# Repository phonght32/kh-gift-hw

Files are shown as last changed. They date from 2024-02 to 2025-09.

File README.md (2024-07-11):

# kh-gift-hw

### 1. Overview

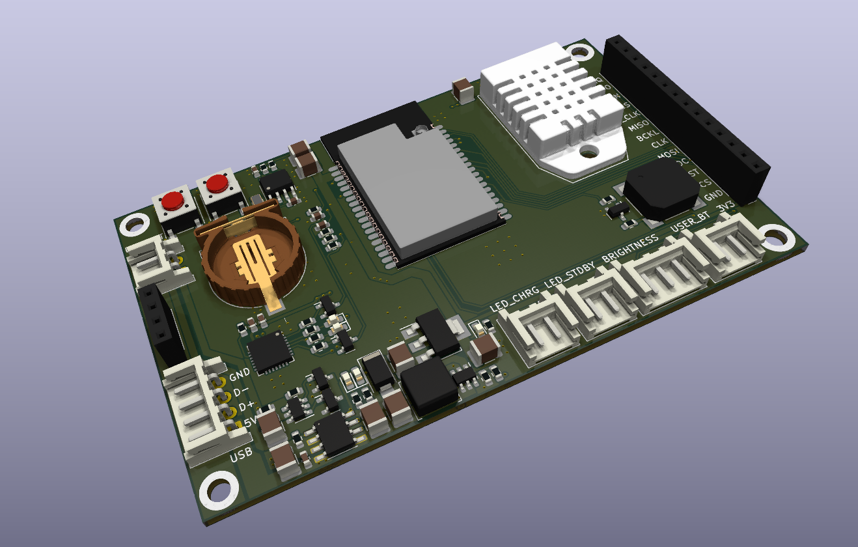
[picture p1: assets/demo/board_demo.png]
board_demo


### 2. Specifications

| Items | Specifications |
| --- | --- |
| Power supply | Pin LiPo 1 cell |
| Microcontroller  | ESP32 |
| LEDs and Buttons | LED Charge<br />LED Standby<br />User push button |
| Dimensions | 89.4 x55 mm<br />Screw hole 83.4 x 49 mm |

### 3. Hardware design

#### Schematic

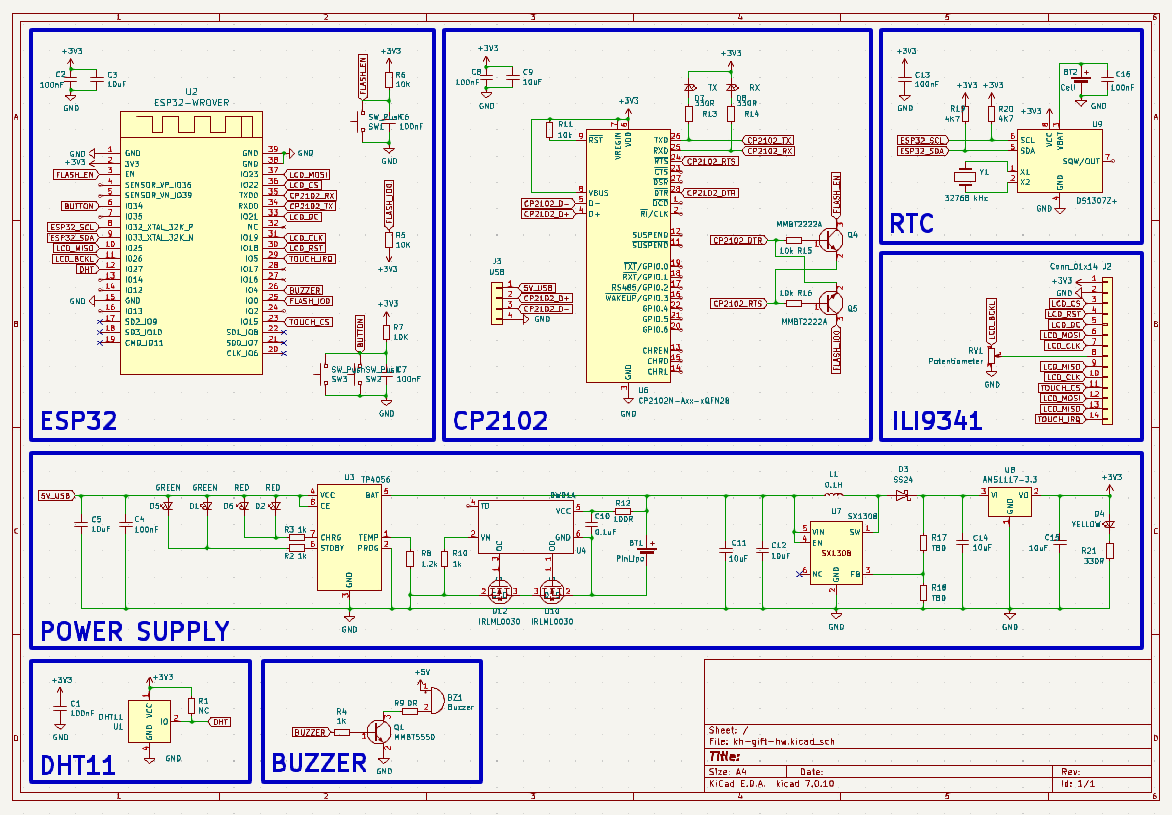
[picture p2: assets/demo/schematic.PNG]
schematic


#### PCB Top

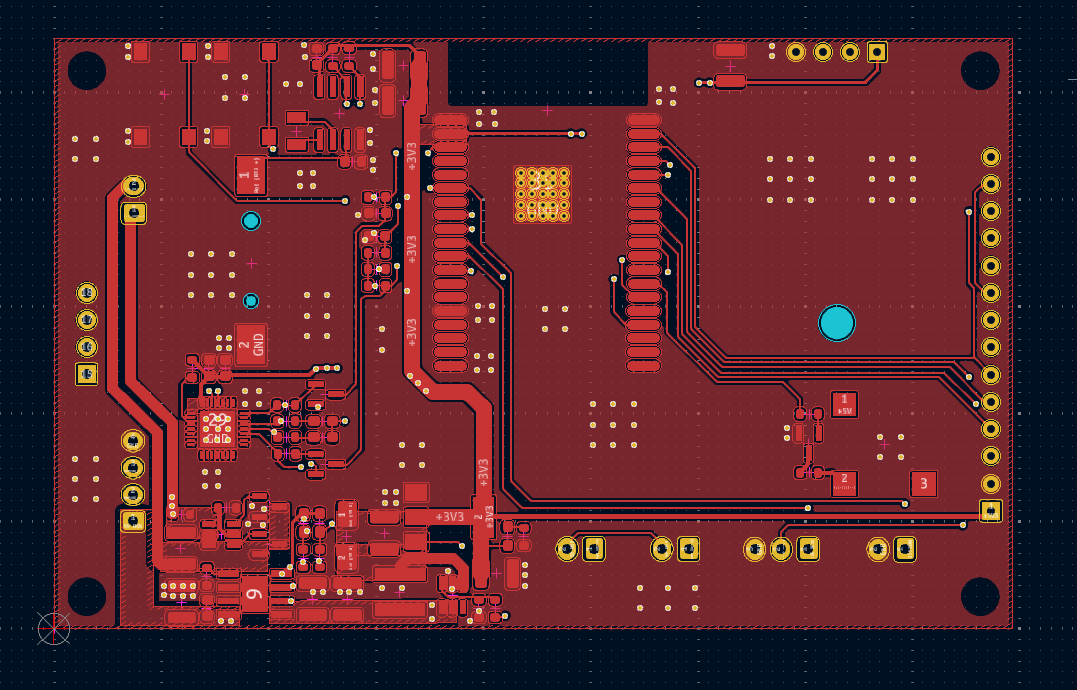
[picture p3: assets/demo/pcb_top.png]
pcb_top


#### PCB Bot

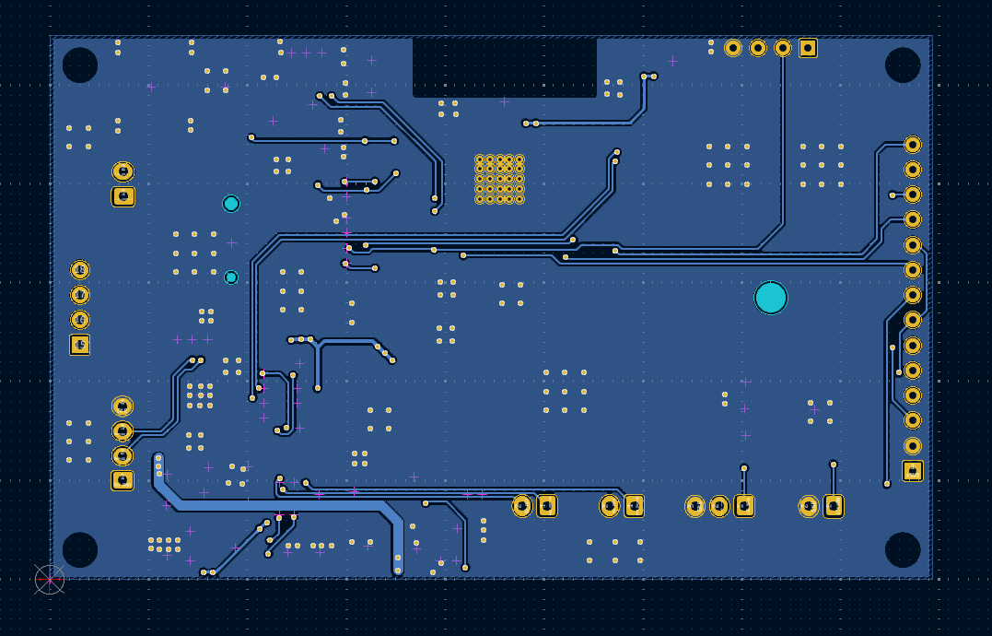
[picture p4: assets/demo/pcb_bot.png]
pcb_bot


#### Dimension

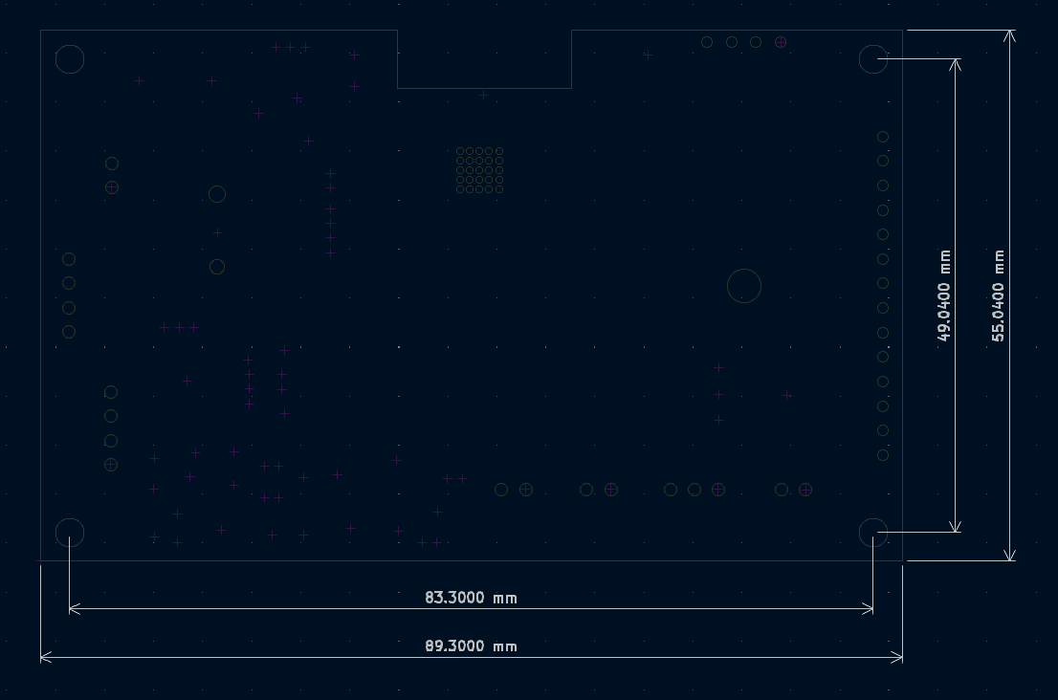
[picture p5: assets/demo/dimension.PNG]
dimension


#### 3D Top

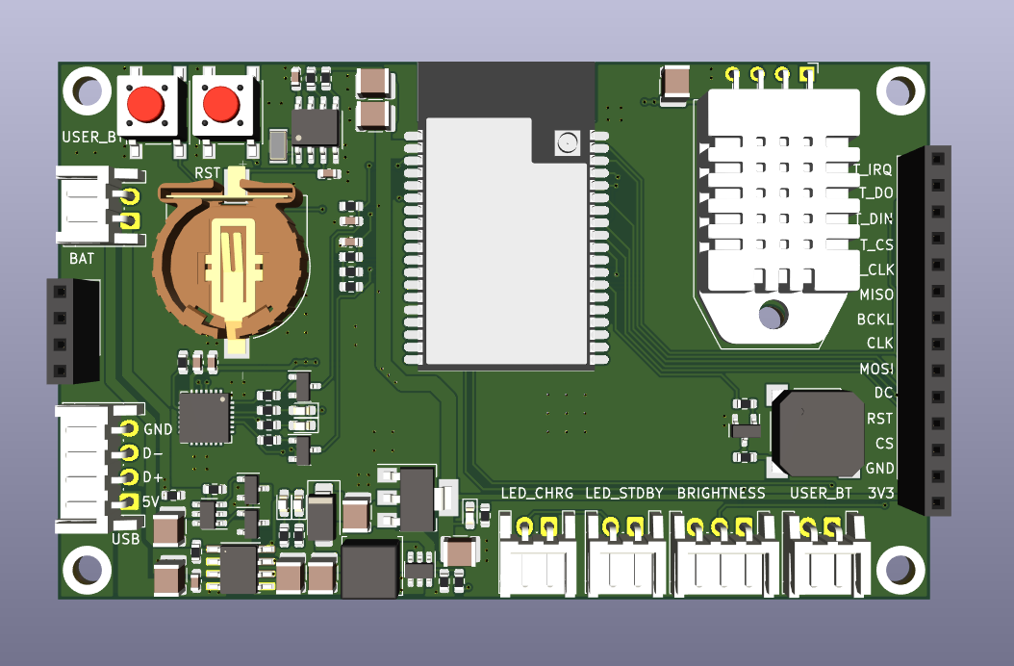
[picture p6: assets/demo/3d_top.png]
3d_top


#### 3D Bot

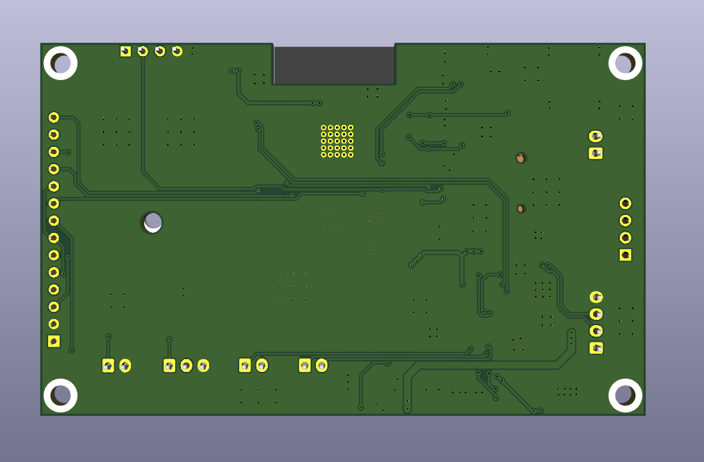
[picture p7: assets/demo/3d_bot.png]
3d_bot


### 4. Bill of Materials (BOM)

[Download v2.0](assets/BOM/BOM_kh-gift-hw_v2.0.xlsx)

### 5. Gerber

[Download v1.0](assets/Gerber/Gerber_kh-gift-hw_v1.0.zip)

[Download v2.0](assets/Gerber/Gerber_kh-gift-hw_v2.0.zip)

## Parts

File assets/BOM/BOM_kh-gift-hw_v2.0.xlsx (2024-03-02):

Reference | Value | Footprint | Qty
BT1 | PinLipo | footprints:JST_EH_S2B-EH_1x02_P2.5mm_Horizontal | 1
BT2 | Cell | footprints:BAT_CR1220_Holder | 1
BZ1 | Buzzer | Buzzer_Beeper:MagneticBuzzer_Kobitone_254-EMB84Q-RO | 1
C1,C2 | 100nF | Capacitor_SMD:C_1210_3225Metric | 2
C3,C5,C11,C12,C14,C15 | 10uF | Capacitor_SMD:C_1210_3225Metric | 6
C4,C6,C7,C8,C13,C16 | 100nF | Capacitor_SMD:C_0603_1608Metric | 6
C9 | 10uF | Capacitor_SMD:C_0603_1608Metric | 1
C10 | 0.1uF | Capacitor_SMD:C_1210_3225Metric | 1
D1 | GREEN | LED_SMD:LED_0603_1608Metric_Pad1.05x0.95mm_HandSolder | 1
D2 | RED | LED_SMD:LED_0603_1608Metric_Pad1.05x0.95mm_HandSolder | 1
D3 | SS24 | Diode_SMD:D_SMA | 1
D4 | YELLOW | LED_SMD:LED_0603_1608Metric_Pad1.05x0.95mm_HandSolder | 1
D5 | GREEN | footprints:JST_EH_S2B-EH_1x02_P2.5mm_Horizontal | 1
D6 | RED | footprints:JST_EH_S2B-EH_1x02_P2.5mm_Horizontal | 1
D7 | TX | LED_SMD:LED_0603_1608Metric_Pad1.05x0.95mm_HandSolder | 1
D8 | RX | LED_SMD:LED_0603_1608Metric_Pad1.05x0.95mm_HandSolder | 1
J2 | Conn_01x14 | footprints:ili9341_3.2inch | 1
J3 | USB | footprints:JST_EH_S4B-EH_1x04_P2.5mm_Horizontal | 1
L1 | 0.1H | Inductor_SMD:L_Coilcraft_XAL5030-XXX | 1
Q1 | MMBT5550 | Package_TO_SOT_SMD:SOT-23 | 1
Q4,Q5 | MMBT2222A | Package_TO_SOT_SMD:SOT-23 | 2
R1 | NC | Resistor_SMD:R_0603_1608Metric | 1
R2,R3,R10 | 1k | Resistor_SMD:R_0603_1608Metric | 3
R4 | 1K | Resistor_SMD:R_0603_1608Metric | 1
R5,R6,R7 | 10K | Resistor_SMD:R_0603_1608Metric | 3
R8 | 1.2k | Resistor_SMD:R_0603_1608Metric | 1
R9 | 0R | Resistor_SMD:R_0603_1608Metric | 1
R11,R15,R16 | 10k | Resistor_SMD:R_0603_1608Metric | 3
R12 | 100R | Resistor_SMD:R_0603_1608Metric | 1
R13,R14,R21 | 330R | Resistor_SMD:R_0603_1608Metric | 3
R17,R18 | TBD | Resistor_SMD:R_0603_1608Metric | 2
R19,R20 | 4K7 | Resistor_SMD:R_0603_1608Metric | 2
RV1 | Potentiometer | footprints:JST_EH_S3B-EH_1x03_P2.5mm_Horizontal | 1
SW1,SW2 | SW_Push | footprints:PushButton_6x6mm_SMD | 2
SW3 | SW_Push | footprints:JST_EH_S2B-EH_1x02_P2.5mm_Horizontal | 1
U1 | DHT11 | footprints:SNR4-2.54-15.5X12.0X5.5MM | 1
U2 | ESP32-WROVER | footprints:ESP32-WROVER | 1
U3 | TP4056 | footprints:SOP127P600X175-9N | 1
U4 | DW01A | Package_TO_SOT_SMD:TSOT-23-6 | 1
U6 | CP2102N-Axx-xQFN28 | Package_DFN_QFN:QFN-28-1EP_5x5mm_P0.5mm_EP3.35x3.35mm | 1
U7 | SX1308 | Package_TO_SOT_SMD:TSOT-23-6 | 1
U8 | AMS1117-3.3 | Package_TO_SOT_SMD:SOT-223-3_TabPin2 | 1
U9 | DS1307Z+ | Package_SO:SOIC-8_3.9x4.9mm_P1.27mm | 1
U10,U12 | IRLML0030 | Package_TO_SOT_SMD:SOT-23 | 2
Y1 | 32768 kHz | footprints:Crystal_SMD_3215-2Pin_3.2x1.5mm | 1

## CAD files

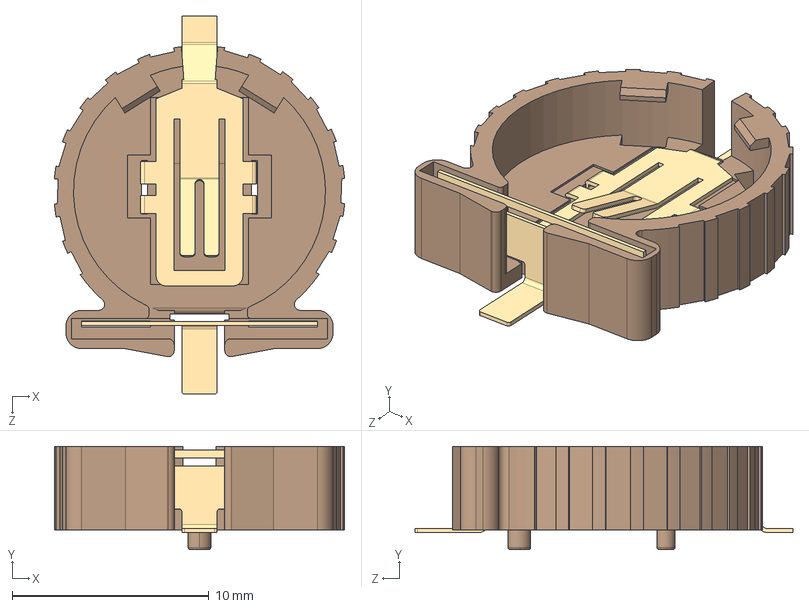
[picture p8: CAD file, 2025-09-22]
Project-Lib/3D/PinHolder_CR1220_SMD.STEP
14.7 x 5.25 x 19.2 mm
S841-HOLDER
S841-LOWER-CONTACT
S841-REAR-CONTACT

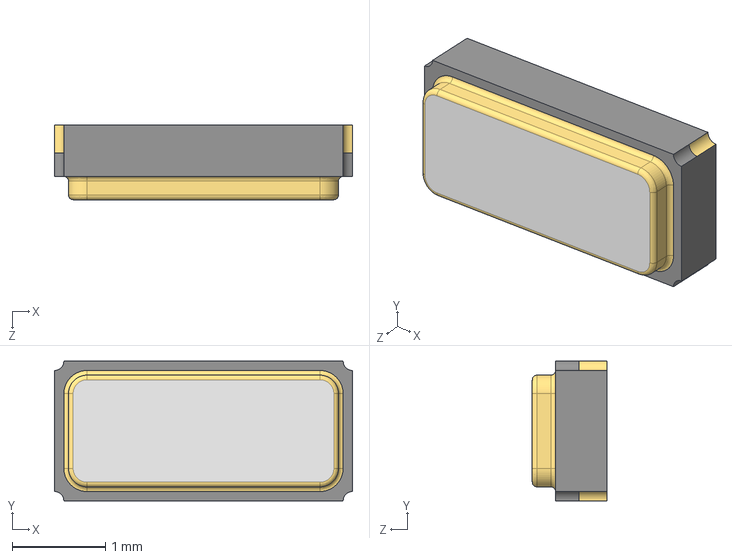
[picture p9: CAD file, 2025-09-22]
Project-Lib/3D/crystal_smd_3215.step
3.20 x 1.50 x 0.8 mm

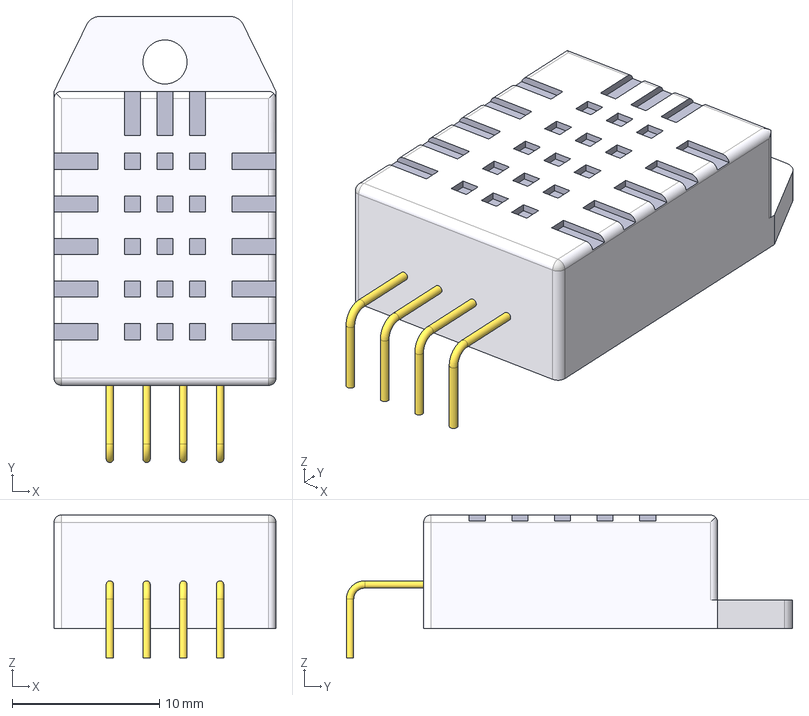
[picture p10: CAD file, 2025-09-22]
Project-Lib/3D/DHT22.stp
15.1 x 30.3 x 9.72 mm

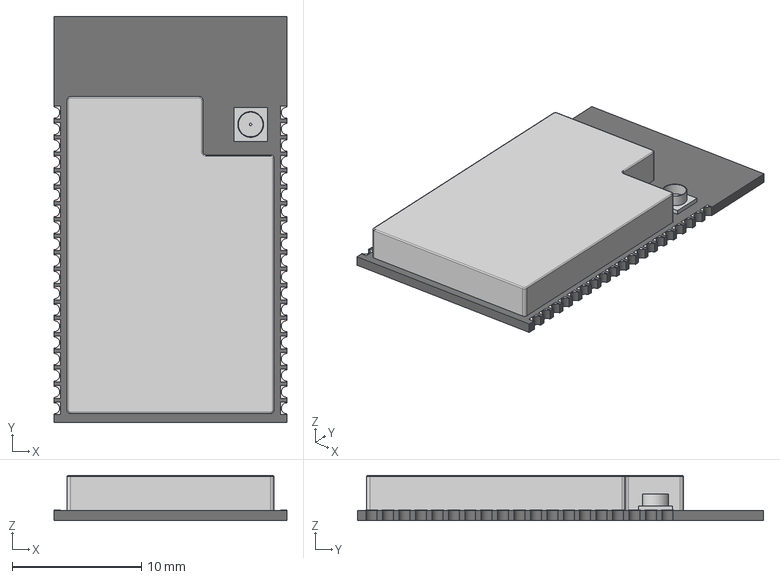
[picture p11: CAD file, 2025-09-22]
Project-Lib/3D/ESP32-Wrover.step
18.0 x 31.4 x 3.50 mm

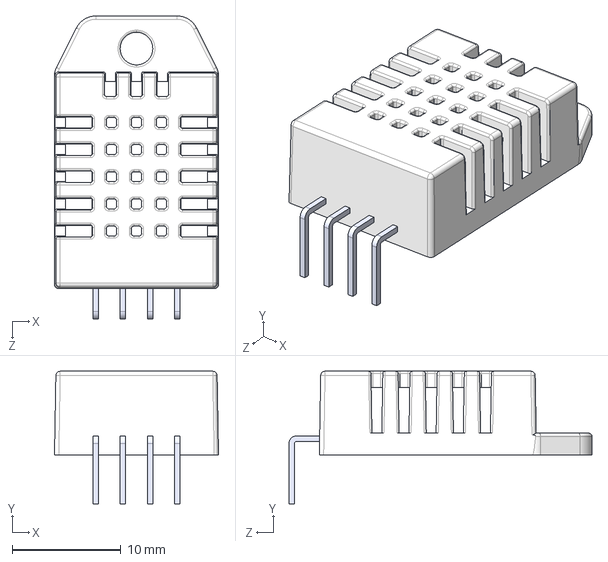
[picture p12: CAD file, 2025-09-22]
Project-Lib/3D/DHT22--3DModel-STEP-56544.STEP
15.1 x 12.2 x 27.9 mm
DHT22 body
pin^DHT22 x 4

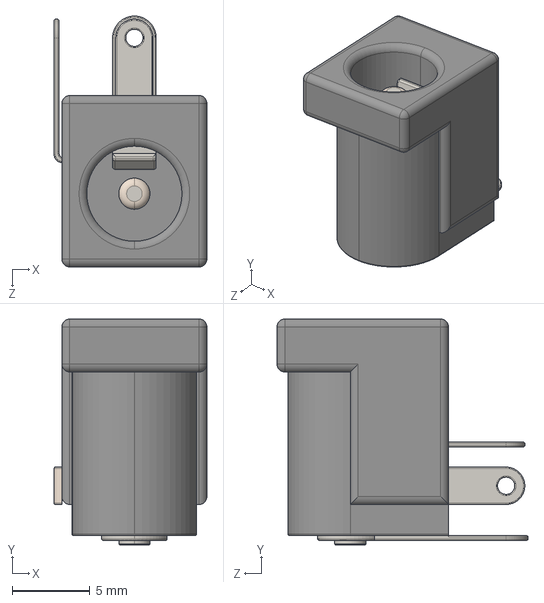
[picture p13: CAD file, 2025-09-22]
Project-Lib/3D/JackDC_5.5mmx2.1mm.step
9.80 x 14.5 x 16.1 mm

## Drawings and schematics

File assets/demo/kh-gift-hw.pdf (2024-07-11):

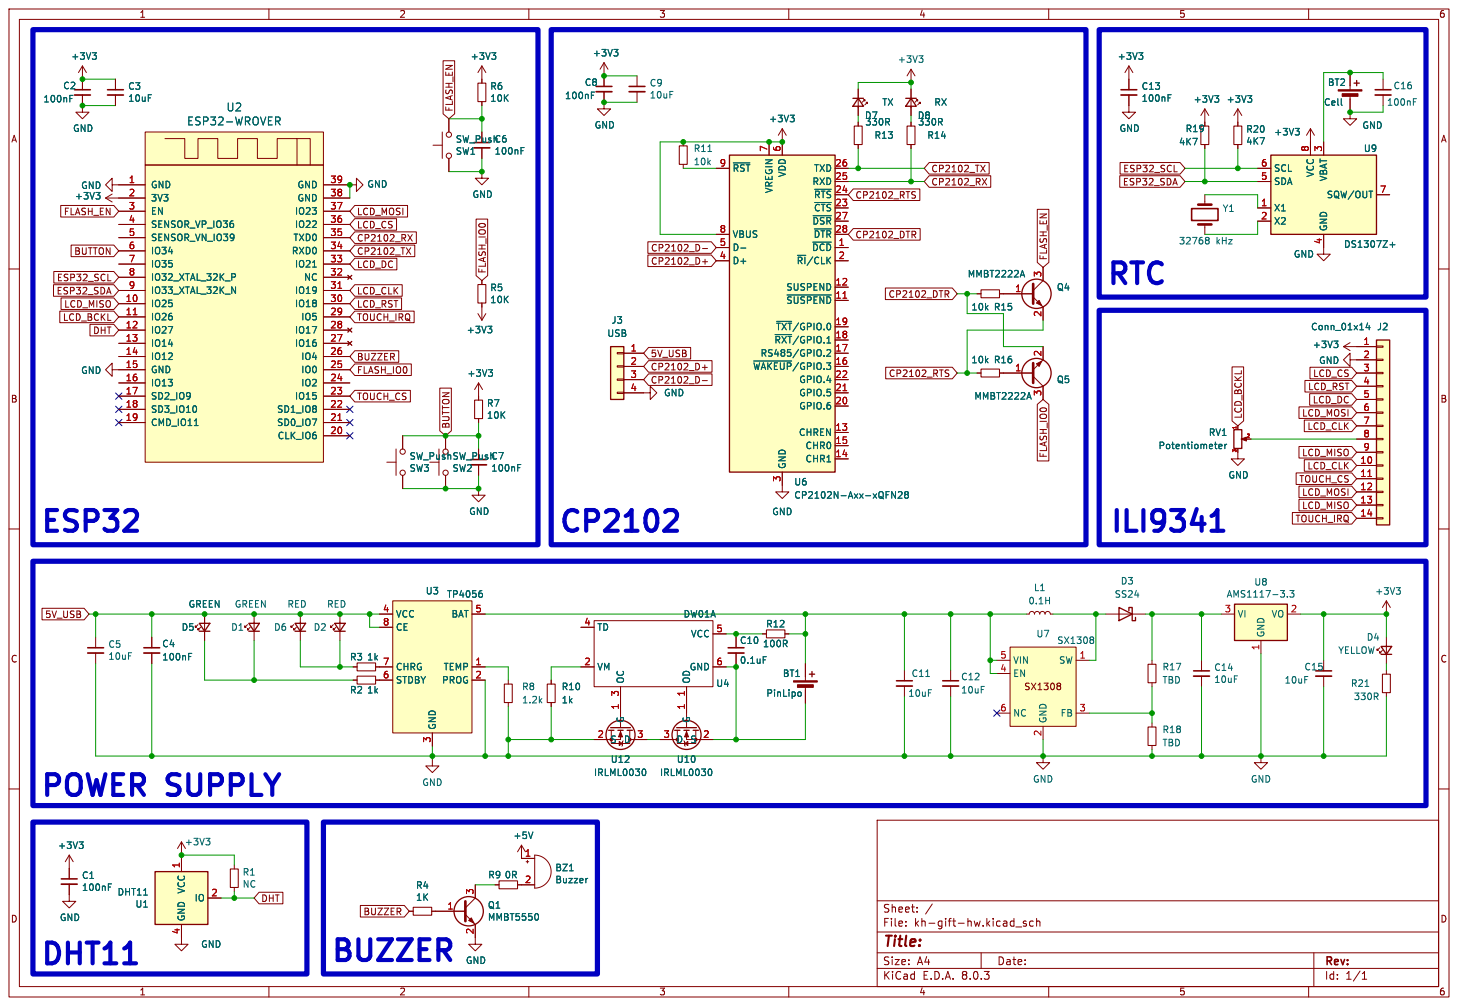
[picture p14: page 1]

7 VBUS 8 ~{RST} 9 U6 CP2102N-Axx-xQFN28 D6 RED GND

4 SDA 5 SCL 6 SQW/OUT 7 VCC

3 VCC 4 BAT 5 STDBY 6 CHRG 7 CE 8 SW3 SW_Push R10

3 VCC 4 BAT 5 STDBY 6 CHRG 7 CE 8 U3 TP4056 C15

2 FB 3 EN 4 VIN 5 NC 6 U7 SX1308 C12

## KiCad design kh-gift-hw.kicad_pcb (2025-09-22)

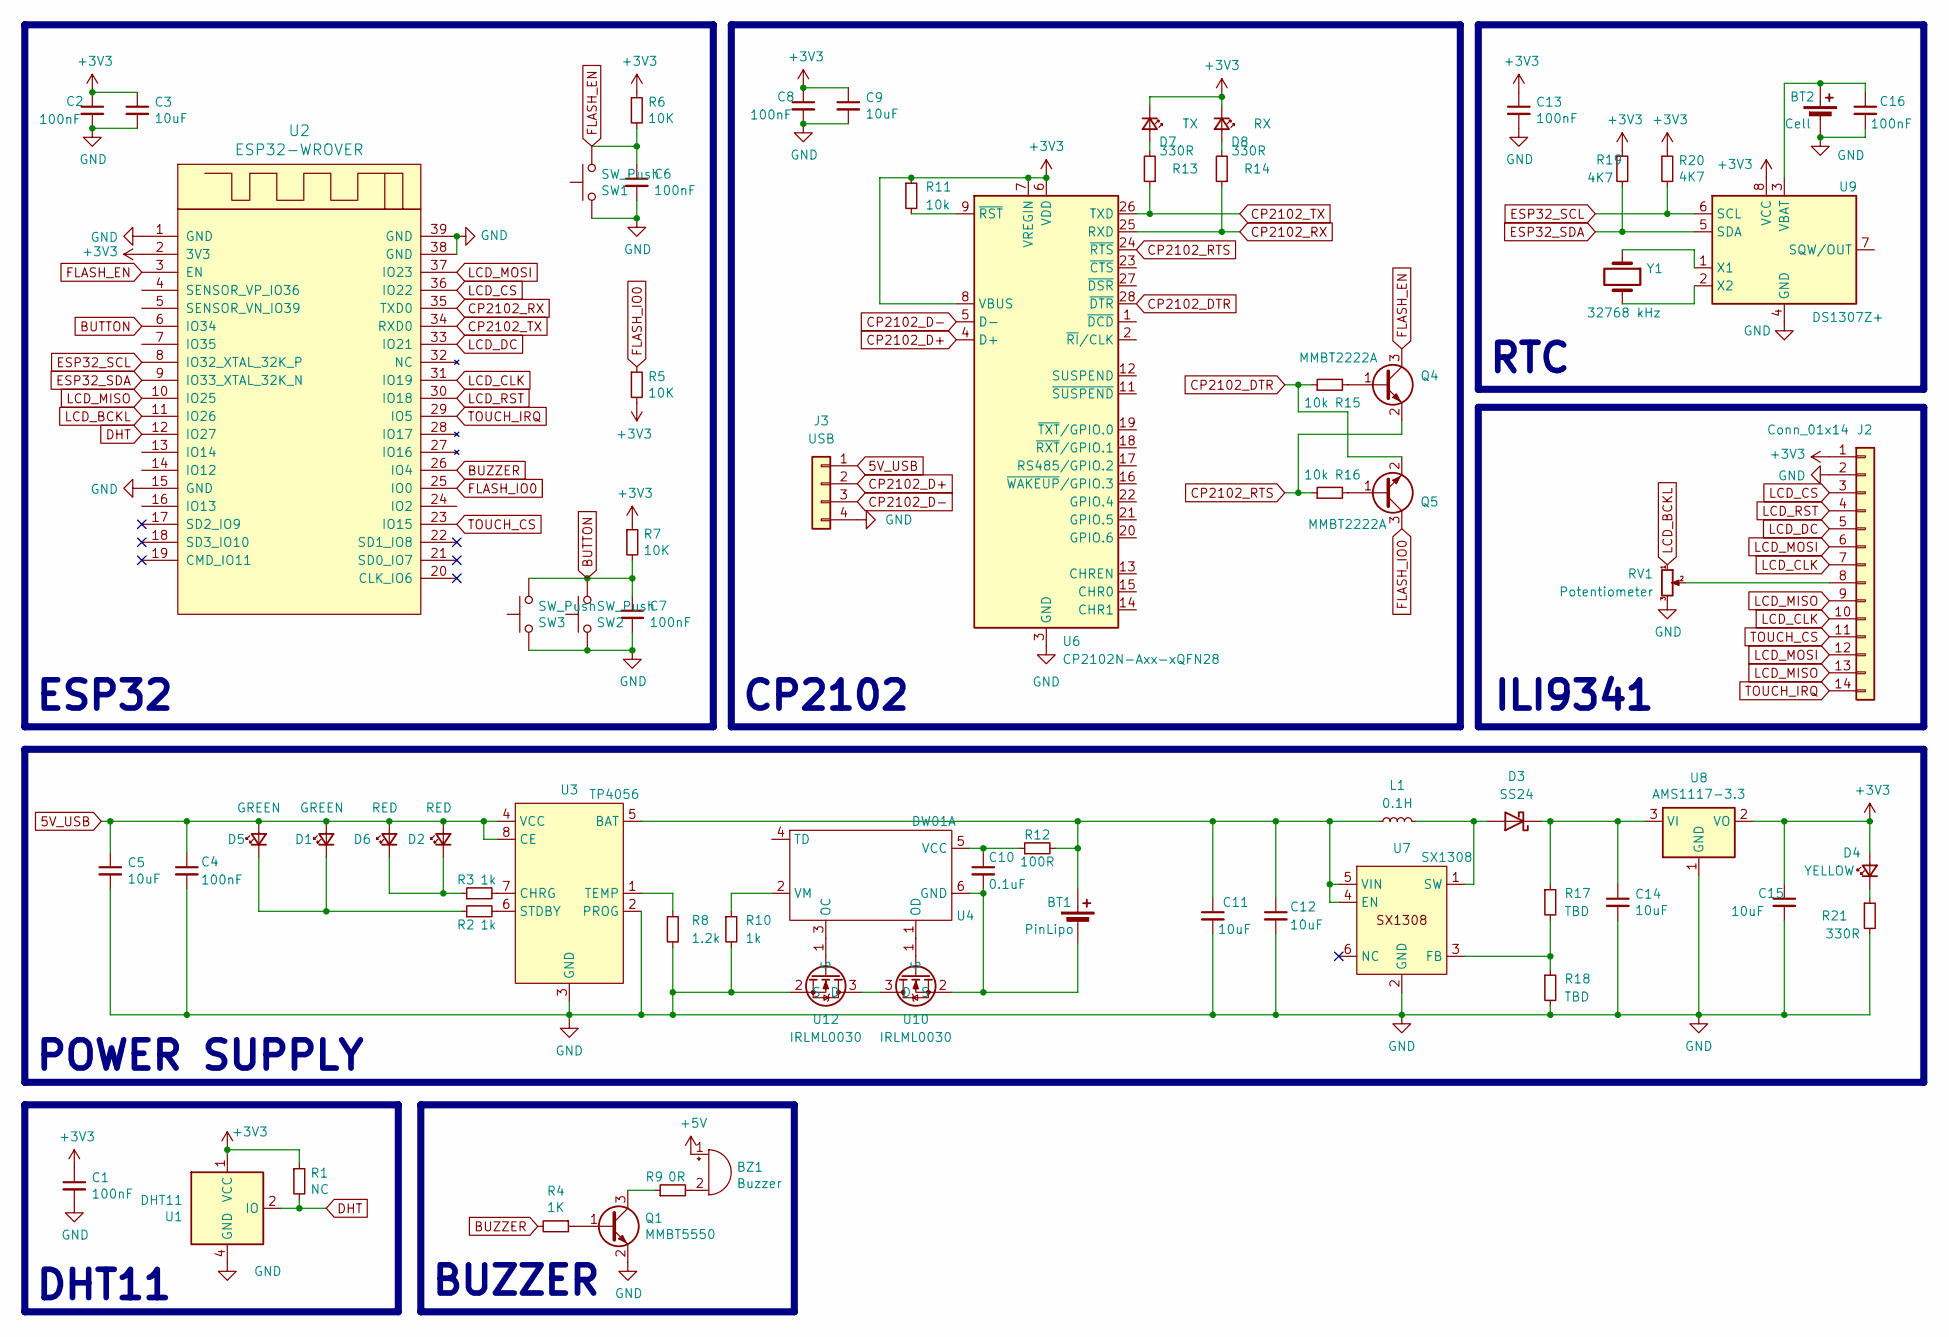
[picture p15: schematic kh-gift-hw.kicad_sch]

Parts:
BT1: PinLipo; JST_EH_S2B-EH_1x02_P2.5mm_Horizontal
BT2: Cell; BAT_CR1220_Holder
BZ1: Buzzer; MagneticBuzzer_Kobitone_254-EMB84Q-RO
C1, C2: 100nF; C_1210_3225Metric
C3, C5, C11, C12, C14, C15: 10uF; C_1210_3225Metric
C4, C6, C7, C8, C13, C16: 100nF; C_0603_1608Metric
C9: 10uF; C_0603_1608Metric
C10: 0.1uF; C_1210_3225Metric
D1: GREEN; LED_0603_1608Metric_Pad1.05x0.95mm_HandSolder
D2: RED; LED_0603_1608Metric_Pad1.05x0.95mm_HandSolder
D3: SS24; D_SMA
D4: YELLOW; LED_0603_1608Metric_Pad1.05x0.95mm_HandSolder
D5: GREEN; Connector_ZH_1x02_P1.25mm_Horizontal
D6: RED; Connector_ZH_1x02_P1.25mm_Horizontal
D7: TX; LED_0603_1608Metric_Pad1.05x0.95mm_HandSolder
D8: RX; LED_0603_1608Metric_Pad1.05x0.95mm_HandSolder
J2: Conn_01x14; ili9341_3.2inch
J3: USB; JST_EH_S4B-EH_1x04_P2.5mm_Horizontal
L1: 0.1H; L_Coilcraft_XAL5030-XXX
Q1: MMBT5550; SOT-23
Q4, Q5: MMBT2222A; SOT-23
R1: NC; R_0603_1608Metric
R2, R3, R10: 1k; R_0603_1608Metric
R4: 1K; R_0603_1608Metric
R5, R6, R7: 10K; R_0603_1608Metric
R8: 1.2k; R_0603_1608Metric
R9: 0R; R_0603_1608Metric
R11, R15, R16: 10k; R_0603_1608Metric
R12: 100R; R_0603_1608Metric
R13, R14, R21: 330R; R_0603_1608Metric
R17, R18: TBD; R_0603_1608Metric
R19, R20: 4K7; R_0603_1608Metric
RV1: Potentiometer; Connector_ZH_1x03_P1.25mm_Horizontal
SW1, SW2: SW_Push; PushButton_6x6mm_SMD
SW3: SW_Push; Connector_ZH_1x02_P1.25mm_Horizontal
U1: DHT11; SNR4-2.54-15.5X12.0X5.5MM
U2: ESP32-WROVER
U3: TP4056; SOP127P600X175-9N
U4: DW01A; TSOT-23-6
U6: CP2102N-Axx-xQFN28; QFN-28-1EP_5x5mm_P0.5mm_EP3.35x3.35mm
U7: SX1308; TSOT-23-6
U8: AMS1117-3.3; SOT-223-3_TabPin2
U9: DS1307Z+; SOIC-8_3.9x4.9mm_P1.27mm
U10, U12: IRLML0030; SOT-23
Y1: 32768 kHz; Crystal_SMD_3215-2Pin_3.2x1.5mm

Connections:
5V_USB: C4.1, C5.1, D1.2 (A), D2.2 (A), D5.2 (A), D6.2 (A), J3.1, U3.4 (VCC), U3.8 (CE)
+3V3: C1.1, C2.1, C3.1, C8.1, C9.1, C13.1, C15.1, D4.2 (A), D7.1 (K), D8.1 (K), J2.1, R1.1, R5.2, R6.1, R7.1, R11.1, R19.1, R20.1, U1.1 (VCC), U2.2 (3V3), U6.6 (VDD), U6.7 (VREGIN), U6.8 (VBUS), U8.2 (VO), U9.8 (VCC)
+5V: BZ1.1 (-)
BUTTON: C7.1, R7.2, SW2.1, SW3.1, U2.6 (IO34)
BUZZER: R4.2, U2.26 (IO4)
CP2102_D+: J3.2, U6.4 (D+)
CP2102_D-: J3.3, U6.5 (D-)
CP2102_DTR: Q5.2 (E), R15.1, U6.28 (~DTR)
CP2102_RTS: Q4.2 (E), R16.1, U6.24 (~RTS)
CP2102_RX: R14.1, U2.35 (TXD0), U6.25 (RXD)
CP2102_TX: R13.1, U2.34 (RXD0), U6.26 (TXD)
DHT: R1.2, U1.2 (IO), U2.12 (IO27)
ESP32_SCL: R20.2, U2.8 (IO32_XTAL_32K_P), U9.6 (SCL)
ESP32_SDA: R19.2, U2.9 (IO33_XTAL_32K_N), U9.5 (SDA)
FLASH_EN: C6.1, Q4.3 (C), R6.2, SW1.1, U2.3 (EN)
FLASH_IO0: Q5.3 (C), R5.1, U2.25 (IO0)
GND: BT2.2 (-), C1.2, C2.2, C3.2, C4.2, C5.2, C6.2, C7.2, C8.2, C9.2, C11.2, C12.2, C13.2, C14.2, C15.2, C16.2, J2.2, J3.4, Q1.2 (E), R8.2, R10.2, R18.2, R21.2, RV1.3, SW1.2, SW2.2, SW3.2, U1.4 (GND), U2.1 (GND), U2.15 (GND), U2.38 (GND), U2.39 (GND), U3.2 (PROG), U3.3 (GND), U6.3 (GND), U6.29 (GND), U7.2 (GND), U8.1 (GND), U9.4 (GND), U12.2 (S)
LCD_BCKL: RV1.1, U2.11 (IO26)
LCD_CLK: J2.7, J2.10, U2.31 (IO19)
LCD_CS: J2.3, U2.36 (IO22)
LCD_DC: J2.5, U2.33 (IO21)
LCD_MISO: J2.9, J2.13, U2.10 (IO25)
LCD_MOSI: J2.6, J2.12, U2.37 (IO23)
LCD_RST: J2.4, U2.30 (IO18)
unnamed: BT1.1 (+), C11.1, C12.1, L1.1, R12.2, U3.5 (BAT), U7.4 (EN), U7.5 (VIN)
unnamed: BT1.2 (-), C10.2, U4.6 (GND), U10.2 (S)
unnamed: BT2.1 (+), C16.1, U9.3 (VBAT)
unnamed: BZ1.2 (+), R9.2
unnamed: D1.1 (K), D5.1 (K), R2.1
unnamed: D2.1 (K), D6.1 (K), R3.1
unnamed: D3.2 (A), L1.2, U7.1 (SW)
unnamed: C14.1, D3.1 (K), R17.1, U8.3 (VI)
unnamed: D4.1 (K), R21.1
unnamed: D7.2 (A), R13.2
unnamed: D8.2 (A), R14.2
unnamed: J2.8, RV1.2
unnamed: Q1.1 (B), R4.1
unnamed: Q1.3 (C), R9.1
unnamed: Q4.1 (B), R15.2
unnamed: Q5.1 (B), R16.2
unnamed: R3.2, U3.7 (CHRG)
unnamed: R2.2, U3.6 (STDBY)
unnamed: R8.1, U3.1 (TEMP)
unnamed: C10.1, R12.1, U4.5 (VCC)
unnamed: R10.1, U4.2 (VM)
unnamed: R11.2, U6.9 (~RST)
unnamed: R17.2, R18.1, U7.3 (FB)
unnamed: U9.1 (X1), Y1.1
unnamed: U9.2 (X2), Y1.2
unnamed: U10.3 (D), U12.3 (D)
unnamed: U4.1 (OD), U10.1 (G)
unnamed: U4.3 (OC), U12.1 (G)
TOUCH_CS: J2.11, U2.23 (IO15)
TOUCH_IRQ: J2.14, U2.29 (IO5)

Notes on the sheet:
ESP32
RTC
POWER SUPPLY
DHT11
ILI9341
BUZZER
CP2102

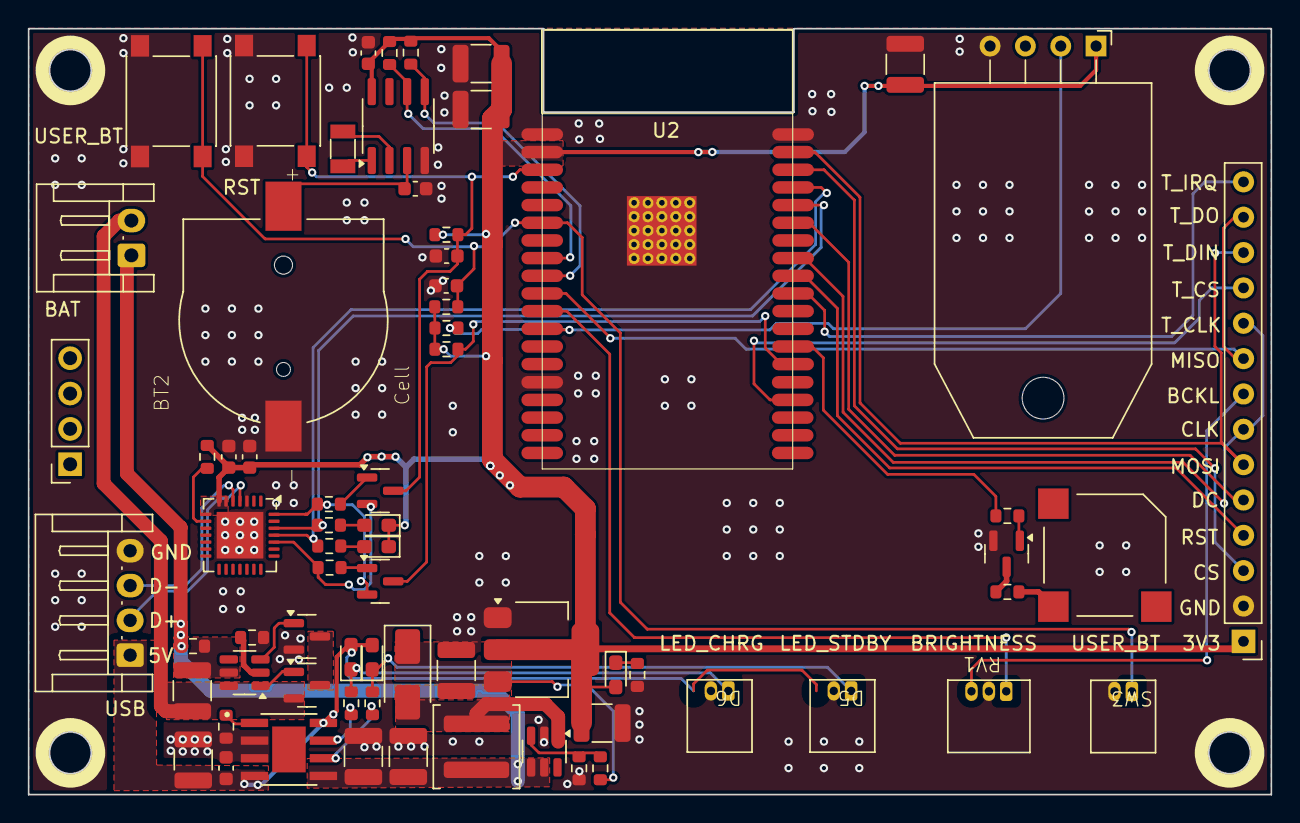
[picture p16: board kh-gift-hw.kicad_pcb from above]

Board: 2 copper layers, 89.3 x 55.0 mm, 69 parts (0 on the bottom side), 53 nets.

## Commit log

2021-01-29 add basic
    [kh-gift-hw.kicad_pcb, kh-gift-hw.sch]
2021-01-31 complete project
    [kh-gift-hw-B_Cu.gbr, kh-gift-hw-B_Mask.gbr, kh-gift-hw-B_Paste.gbr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]
2024-01-06 remove kicad-library
2024-01-14 update library
    [DHT22--3DModel-STEP-56544.STEP, DHT22.stp, ESP32-Wrover.step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]
2024-01-14 update routing
    [kh-gift-hw.kicad_pcb, kh-gift-hw.kicad_sch]
2024-02-07 update board shape
2024-02-07 update pcb
    [kh-gift-hw.kicad_pcb, kh-gift-hw.kicad_sch]
2024-02-07 update demo
    [kh-gift-hw.kicad_pcb]
2024-02-07 remove pin 1 notify
2024-02-07 add USB pinout description
    [kh-gift-hw.kicad_pcb]
2024-03-02 update gerber
    [kh-gift-hw-B_Cu.gbr, kh-gift-hw-B_Mask.gbr, kh-gift-hw-B_Paste.gbr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]
2024-03-02 update project setting for Kicad v8
    [kh-gift-hw.kicad_pcb, kh-gift-hw.kicad_sch]
2024-03-02 add BOM
    [kh-gift-hw.xlsx]
2024-07-11 update project
    [kh-gift-hw.kicad_pcb]
2024-07-11 remove gerber folder
    [kh-gift-hw-B_Cu.gbr, kh-gift-hw-B_Mask.gbr, kh-gift-hw-B_Paste.gbr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]
2024-07-11 update BOM
    [BOM_kh-gift-hw_v2.0.xlsx]
2025-09-22 update footprint
    [DHT22--3DModel-STEP-56544.STEP, DHT22.stp, ESP32-Wrover.step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]
